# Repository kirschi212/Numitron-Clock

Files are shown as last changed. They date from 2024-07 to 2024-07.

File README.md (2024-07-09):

# Numitron Clock by Kirschi

This is a small documentation if you want to build a Numitron Clock by yourself. This project is build around IV-9 tubes, an ESP8266 and the MAX7315 IO-Expander.

## Images





## Functioning

The ESP8266 is connected to the WiFi and retrieves the current time from a time server. The MAX7315 IO expanders are then controlled by the ESP8266 via I2C and switch the corresponding segments of the Numitron segments.
Optionally, a switch can also be installed with which the tubes can be switched off.

------

## Parts list

### Main Components:

Component  | Quantity | Description |
------------- | ------------- | ------------- |
ESP8266 NodeMCU  | 1 | heart of the circuit |
IV-9 numitron tubes | 4 | retro 7 segment displays |
MAX7315AEE+ | 4 | 8-bit IO-Expanders |
Custom PCB | 1 | Eagle.CAD files are uploaded in this repository |

### Other Components:

| Component  | Quantity | Description |
| --- | --- | --- |
| Resistor 0603 47Ω  | 32  | current limiting resistors for numitron segments |
| Resistor 0603 4.7kΩ  | 2  | pull-up resistors for I2C-Bus |
| Ceramic capacitors  0603 0.047µF  | 4  | decoupling capacitors for MAX7315 |
| USB-C panel jack  | 1  | used for power supply via USB-C |
                    
### Optional Components:
These components can optionally be installed.

| Component  | Quantity | Description |
| --- | --- | --- |
| Resistor 0603 10kΩ  | 1 | pull-up resistor for switch |
| Electrolytic capacitor 100µF | 1  | capacitor for voltage stabilization |
| Mechanical switch  | 1  | used for turning all segments on or off |

##### Notice: Either the electrolytic capacitor OR switch can be installed with this version of the PCB-design.

## PCB: schematic and board

#### Notice: This current version of the PCB shows some minor mistakes, e.g. the electrolytic capacitor can only be placed without installing a switch. Nevertheless the board is fully functional! If you are interested, I could design a second version of this board and I will try to improve it!





## Casing

In the repository you can find the Fusion360 file to the casing that I designed myself. It features mounting holes for the PCB, cutouts for the USB-C panel jack and the switch. You can print it with a common 3D-printer using PLA or PETG.

------
## Code

The code was designed to be uploaded to the ESP8266 via the Arduino IDE and a USB-connection. 



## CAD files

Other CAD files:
F3D file for casing/numitron-clock-case.f3d

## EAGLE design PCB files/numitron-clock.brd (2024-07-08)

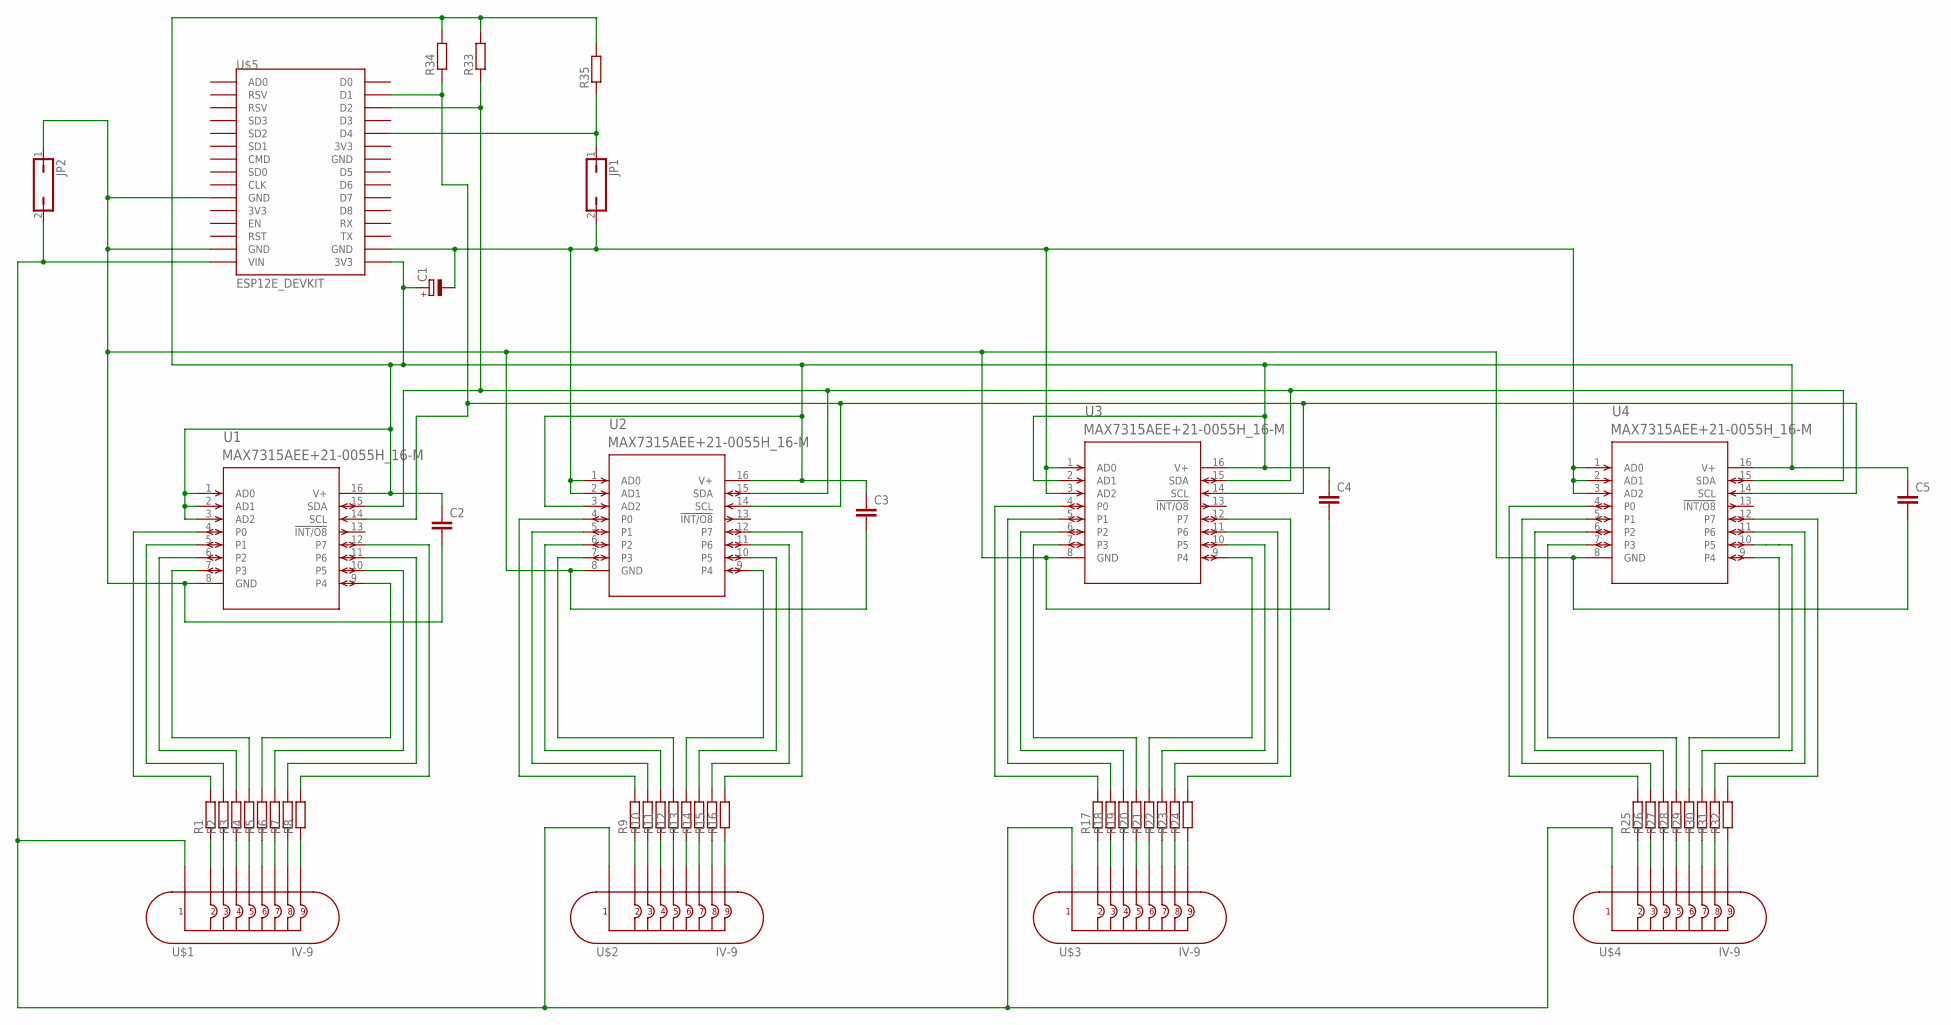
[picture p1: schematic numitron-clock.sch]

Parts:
C1: CPOL-EUE2,5-6E; E2,5-6E
C2, C3, C4, C5: C-EUC0603; C0603
JP1, JP2: JP1Q; JP1
R1, R2, R3, R4, R5, R6, R7, R8, R9, R10, R11, R12, R13, R14, R15, R16, R17, R18, R19, R20, R21, R22, R23, R24, R25, R26, R27, R28, R29, R30, R31, R32, R33, R34, R35: R-EU_R0603; R0603
U1, U2, U3, U4: MAX7315AEE+21-0055H_16-M; 21-0055H_16-M
U$1, U$2, U$3, U$4: IV-9
U$5: ESP12E_DEVKIT

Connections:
unnamed: R1.1, U$1.2
unnamed: R2.1, U$1.3
unnamed: R3.1, U$1.4
unnamed: R4.1, U$1.5
unnamed: R5.1, U$1.6
unnamed: R6.1, U$1.7
unnamed: R7.1, U$1.8
unnamed: R8.1, U$1.9
unnamed: R1.2, U1.4 (P0)
unnamed: R33.1, U1.15 (SDA), U2.15 (SDA), U3.15 (SDA), U4.15 (SDA), U$5.D2
unnamed: R34.1, U1.14 (SCL), U2.14 (SCL), U3.14 (SCL), U4.14 (SCL), U$5.D1
unnamed: R2.2, U1.5 (P1)
unnamed: JP2.2, U$1.1, U$2.1, U$3.1, U$4.1, U$5.VIN
unnamed: R3.2, U1.6 (P2)
unnamed: R4.2, U1.7 (P3)
unnamed: R5.2, U1.9 (P4)
unnamed: C1.+, C2.1, C3.1, C4.1, C5.1, R33.2, R34.2, R35.2, U1.1 (AD0), U1.2 (AD1), U1.3 (AD2), U1.16 (V+), U2.3 (AD2), U2.16 (V+), U3.2 (AD1), U3.16 (V+), U4.16 (V+), U$5.3V3@2 (3V3)
unnamed: R6.2, U1.10 (P5)
unnamed: R7.2, U1.11 (P6)
unnamed: R8.2, U1.12 (P7)
unnamed: R12.2, U2.7 (P3)
unnamed: R11.2, U2.6 (P2)
unnamed: R10.2, U2.5 (P1)
unnamed: R9.2, U2.4 (P0)
unnamed: R13.2, U2.9 (P4)
unnamed: R14.2, U2.10 (P5)
unnamed: R15.2, U2.11 (P6)
unnamed: R16.2, U2.12 (P7)
unnamed: R17.2, U3.4 (P0)
unnamed: R18.2, U3.5 (P1)
unnamed: R19.2, U3.6 (P2)
unnamed: R20.2, U3.7 (P3)
unnamed: R21.2, U3.9 (P4)
unnamed: R22.2, U3.10 (P5)
unnamed: R23.2, U3.11 (P6)
unnamed: R24.2, U3.12 (P7)
unnamed: R25.2, U4.4 (P0)
unnamed: R26.2, U4.5 (P1)
unnamed: R27.2, U4.6 (P2)
unnamed: R28.2, U4.7 (P3)
unnamed: R29.2, U4.9 (P4)
unnamed: R30.2, U4.10 (P5)
unnamed: R31.2, U4.11 (P6)
unnamed: R32.2, U4.12 (P7)
unnamed: JP1.1, R35.1, U$5.D4
unnamed: C2.2, C3.2, C4.2, C5.2, JP2.1, U1.8 (GND), U2.8 (GND), U3.8 (GND), U4.8 (GND), U$5.GND@0 (GND), U$5.GND@1 (GND)
unnamed: C1.-, JP1.2, U2.1 (AD0), U2.2 (AD1), U3.1 (AD0), U3.3 (AD2), U4.1 (AD0), U4.2 (AD1), U4.3 (AD2), U$5.GND@3 (GND)
unnamed: R25.1, U$4.2
unnamed: R26.1, U$4.3
unnamed: R27.1, U$4.4
unnamed: R28.1, U$4.5
unnamed: R29.1, U$4.6
unnamed: R30.1, U$4.7
unnamed: R31.1, U$4.8
unnamed: R32.1, U$4.9
unnamed: R17.1, U$3.2
unnamed: R18.1, U$3.3
unnamed: R19.1, U$3.4
unnamed: R20.1, U$3.5
unnamed: R21.1, U$3.6
unnamed: R22.1, U$3.7
unnamed: R23.1, U$3.8
unnamed: R24.1, U$3.9
unnamed: R9.1, U$2.2
unnamed: R10.1, U$2.3
unnamed: R11.1, U$2.4
unnamed: R12.1, U$2.5
unnamed: R13.1, U$2.6
unnamed: R14.1, U$2.7
unnamed: R15.1, U$2.8
unnamed: R16.1, U$2.9

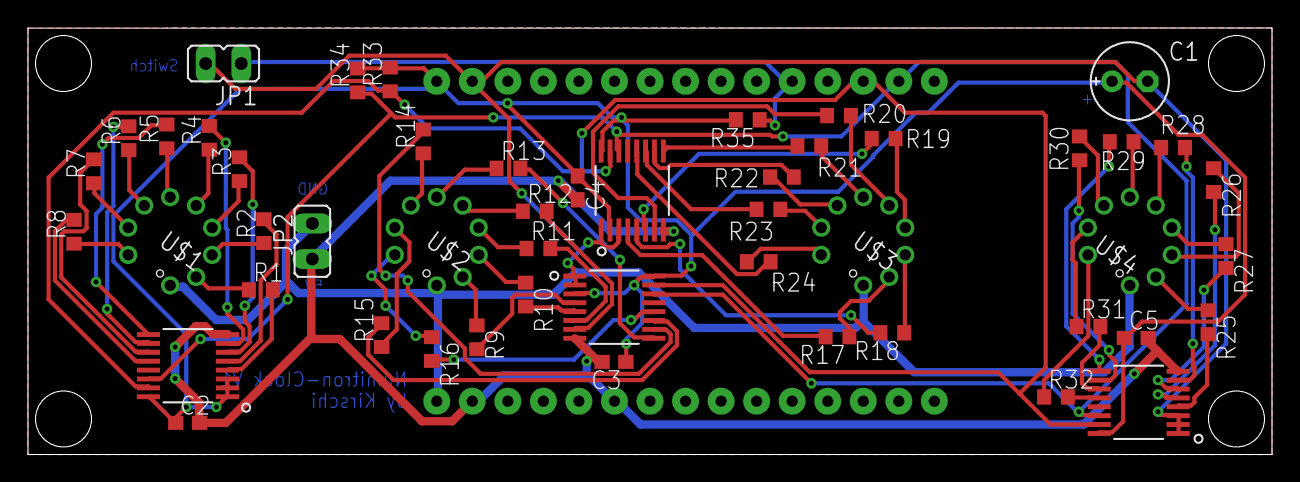
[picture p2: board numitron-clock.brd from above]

Board: 2 copper layers, 88.9 x 30.5 mm, 51 parts (1 on the bottom side), 71 nets.

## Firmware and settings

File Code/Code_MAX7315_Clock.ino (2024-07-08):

/* Please notice: All code regarding the setup of the WiFi and pulling the current from the time-server were not created by me.
 * Source of code: https://polluxlabs.net/esp8266-projekte/die-aktuelle-uhrzeit-mit-einem-esp8266-abfragen/
 */

#include <Wire.h>
#include <ESP8266WiFi.h>
#include <time.h>

// WiFi credentials
#ifndef STASSID
#define STASSID "XXX"    // set your SSID
#define STAPSK  "XXX" // set your WiFi password
#endif

// NTP configuration
#define MY_NTP_SERVER "0.de.pool.ntp.org"           
#define MY_TZ "CET-1CEST,M3.5.0/02,M10.5.0/03"   

// I2C Configuration
#define I2C_SDA 4
#define I2C_SCL 5

#define BUTTON 2

// I2C Expander Addresses
const int MAX1 = 0x27;
const int MAX2 = 0x24;
const int MAX3 = 0x22;
const int MAX4 = 0x20; 

// Number patterns for display
const byte number[] = {
  0b00100001,
  0b11111001,
  0b00010101,
  0b10010001,
  0b11001001,
  0b10000011,
  0b00000011,
  0b11110001,
  0b00000001,
  0b10000001
};

time_t now;                         // these are the seconds since Epoch (1970) - UTC
tm tm;

int button_state = 1;
bool second_state = false;
unsigned long lastSecondChange = 0;
unsigned long lastButtonChange = 0;

// Function to write a single byte to a register on an I2C device
int writeRegister(const int address, byte reg, byte val) {
  Wire.beginTransmission(address);
  Wire.write(reg);
  Wire.write(val);
  return Wire.endTransmission();
}

// Function to initialize I2C expanders
void initI2CExpander(const int address) {
  writeRegister(address, 0x03, 0x00); // Set all ports to outputs (configuration register)
  writeRegister(address, 0x01, 0xFF); // Turn off all outputs initially
}

// Function to write a number to a specific I2C expander
int writeNumberToExpander(const int address, byte val) {
  return writeRegister(address, 0x01, val);
}

void setup() {
  delay(1000);

  // Initialize I2C communication
  Wire.begin(I2C_SDA, I2C_SCL);
  Wire.setClock(100000);

  // Initialize I2C expanders
  initI2CExpander(MAX1);
  initI2CExpander(MAX2);
  initI2CExpander(MAX3);
  initI2CExpander(MAX4);

  configTime(MY_TZ, MY_NTP_SERVER);
  
  // Initialize WiFi connection
  WiFi.persistent(false);
  WiFi.mode(WIFI_STA);
  WiFi.begin(STASSID, STAPSK);
  while (WiFi.status() != WL_CONNECTED) {
    writeNumberToExpander(MAX4, 0b00000000);
    delay(50);
    writeNumberToExpander(MAX4, 0b00000001);
    delay(50);    
  }

  pinMode(BUTTON, INPUT);
}

void loop() {
  unsigned long currentMillis = millis();
    
  time(&now);                       // read the current time
  localtime_r(&now, &tm);

  int minutes, minute_ones, minute_tens, hours, hour_ones, hour_tens;

  // Check if 500ms went by after last decimal point update
  if (currentMillis - lastSecondChange >= 500) {
    second_state = !second_state; // invert second state
    lastSecondChange = currentMillis; // update time stamp
  }

  if (digitalRead(BUTTON) == LOW) { //read button state (input is pulled up to VCC)
    button_state = 0;
  } else 
  {
    button_state = 1;
  }
  
  hours = tm.tm_hour;
  minutes = tm.tm_min;

  minute_ones = minutes % 10;
  minute_tens = minutes / 10;

  hour_ones = hours % 10;
  hour_tens = hours / 10;

  if (button_state == 1) {
    writeNumberToExpander(MAX1, number[hour_tens]); 
    writeNumberToExpander(MAX2, number[hour_ones]);

    if (second_state) {
      writeNumberToExpander(MAX3, number[minute_tens] ^ 0b00000001); // update minutes with decimal point
      writeNumberToExpander(MAX4, number[minute_ones] ^ 0b00000001); // update minutes with decimal point
    } else {
      writeNumberToExpander(MAX3, number[minute_tens]); // update minutes without decimal point
      writeNumberToExpander(MAX4, number[minute_ones]); // update minutes without decimal point
    }
  } else {        // turn all segments off
    writeNumberToExpander(MAX1, 0xFF);
    writeNumberToExpander(MAX2, 0xFF);
    writeNumberToExpander(MAX3, 0xFF);
    writeNumberToExpander(MAX4, 0xFF);
  }
}

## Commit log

2024-07-08 Added PCB files
    [numitron-clock.brd, numitron-clock.sch]
2024-07-08 Added files for casing
    [numitron-clock-case.f3d]

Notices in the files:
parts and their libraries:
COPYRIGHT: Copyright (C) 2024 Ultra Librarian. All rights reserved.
